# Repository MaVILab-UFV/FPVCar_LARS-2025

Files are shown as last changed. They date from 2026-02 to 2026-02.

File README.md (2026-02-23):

# FPVcar: An Affordable Robotic Platform to Support Computer Vision Education, from Hardware Design to User-Friendly Programming

This repository contains the full source code and 3D design files for the FPVCar project.

FPVcar is a low-cost robotic platform designed to facilitate hands-on Computer Vision and Robotics education, enabling 
users to control a robot through high-level Python commands while receiving real-time video feedback.

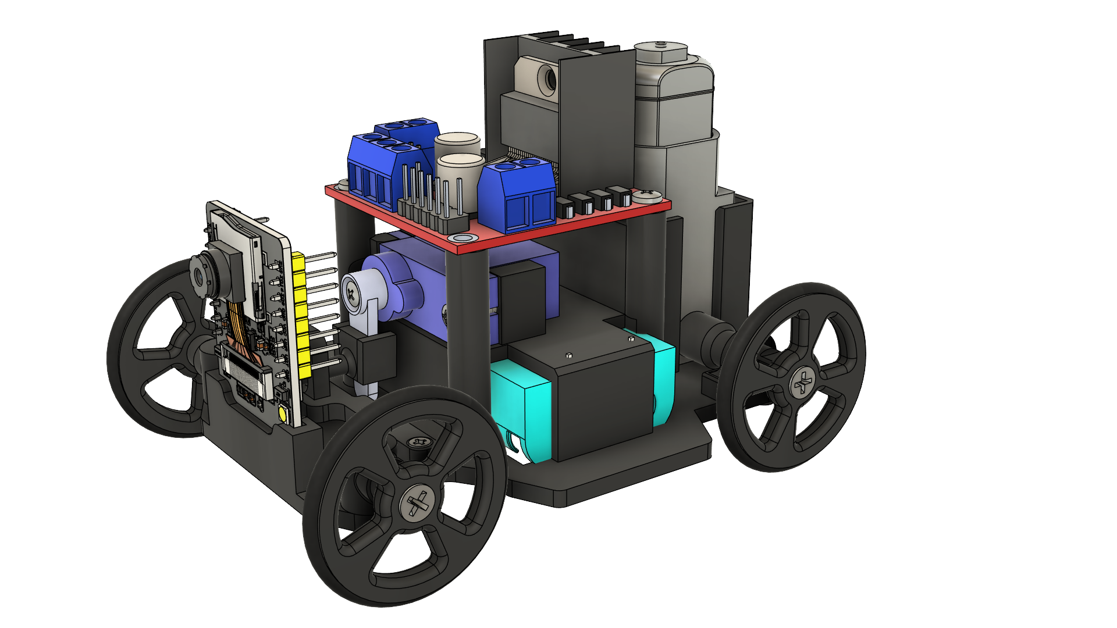
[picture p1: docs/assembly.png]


## Prerequisites
 - Python 3.6+ and python3-venv.
 - PlatformIO, for firmware deployment. 
 - OpenCV, Websockets and Pandas, for the control software.

## Getting Started

### 1. Clone the Repository

First, clone this repository to your local machine:

```bash
git clone https://github.com/MaVILab-UFV/FPVCar_LARS-2025.git
cd FPVCar_LARS-2025
```

### 2. Firmware Deployment
The firmware can be flashed using PlatformIO either via the VS Code Interface or the command line.

#### Setup Credentials
Before flashing, navigate to `firmware/include/` and update `wifikeys.h` with the desired network credentials.

#### 2.1 Using VS Code Extension
Open the `firmware/` folder in VS Code and click on the PlatformIO icon on the left sidebar. Then, under **Project Tasks**, click **Upload**.

#### 2.2 Using Command Line
If you have PlatformIO Core installed, run the following commands in your terminal:
```bash
cd firmware
pio run --target upload
```
### 3. Software Installation
Follow these steps to create a virtual enviroment and install the fpvcar library:
```bash
# Navigate to the software directory
cd software

# Create and activate a virtual environment
python3 -m venv venv
source venv/bin/activate

# Install build tools and dependencies
pip install wheel setuptools
pip install opencv-python websockets

# Build and install the FPVcar package
python3 setup.py bdist_wheel
pip install ./dist/fpvcar-0.1.2-py3-none-any.whl
```

## Running the FPVCar
After turning on the robot and connecting to the same network, you can run various control scripts. Here is an example:
```python
from fpvcar import FPVCar
from fpvcar.command import MoveForwardStraight, Stop

# Initialize the car with its Access Point IP
car = FPVCar(ip='192.168.4.1')
car.start()

# Example: Move forward
car.run(lambda frame, info: MoveForwardStraight)
```
This repository also provides ready-to-use scripts for validation and testing in the `software/tests/` directory.

## Authors

## Laboratory

## Acknowlwdgements

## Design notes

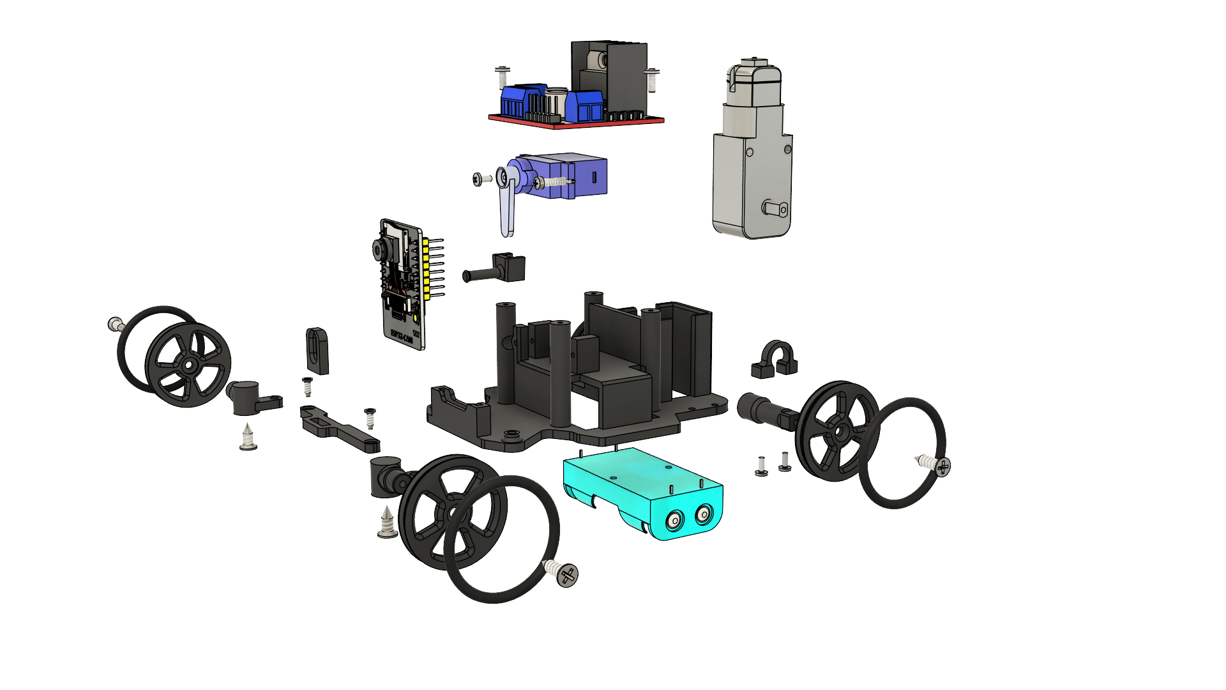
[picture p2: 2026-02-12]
docs/expanded_view.png

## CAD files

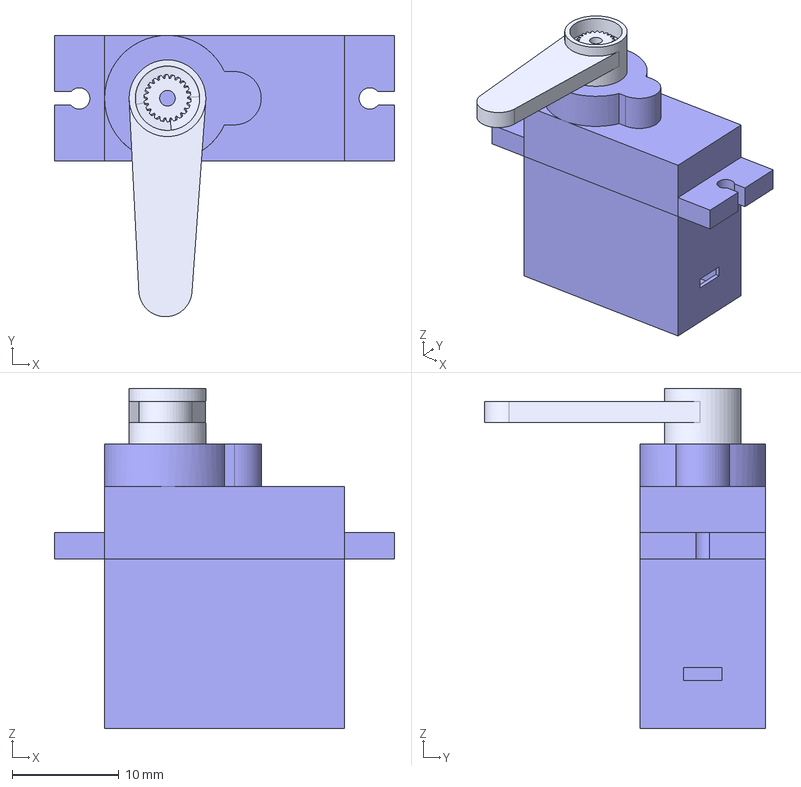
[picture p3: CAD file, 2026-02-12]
hardware/cad/step/servo_motor_assembly.step
31.9 x 26.4 x 31.9 mm
lower cover
Part6^servo motor assembley
Part10^servo motor assembley
upper cover
Part14^servo motor assembley

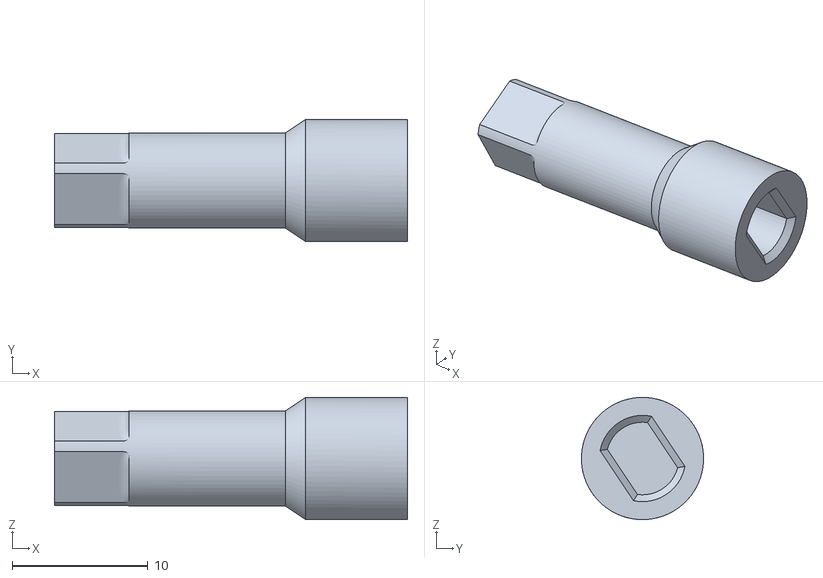
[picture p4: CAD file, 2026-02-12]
hardware/3d_printing/rear_axle.stl
26.0 x 9.00 x 9.00

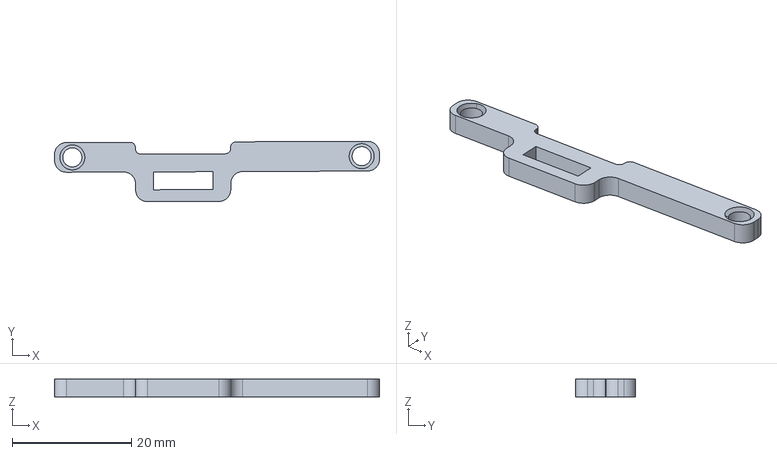
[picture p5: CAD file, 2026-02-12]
hardware/cad/step/steering_arm.step
54.6 x 10.1 x 3.00 mm

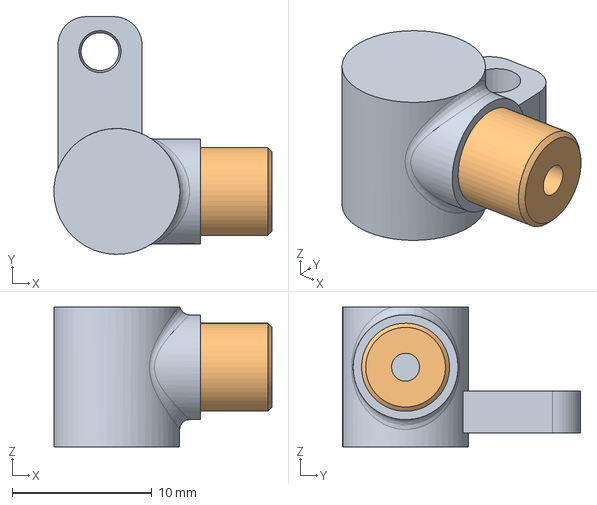
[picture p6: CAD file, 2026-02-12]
hardware/cad/step/left_pivot.step
15.6 x 17.0 x 10.0 mm

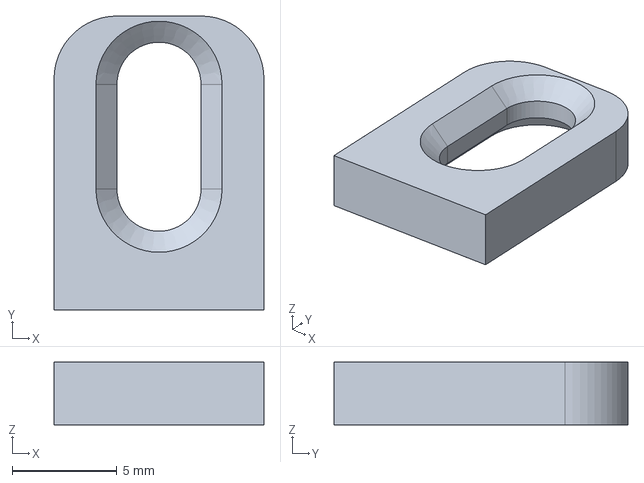
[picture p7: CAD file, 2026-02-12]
hardware/cad/step/arm_fitting.step
10.00 x 14.0 x 3.00 mm

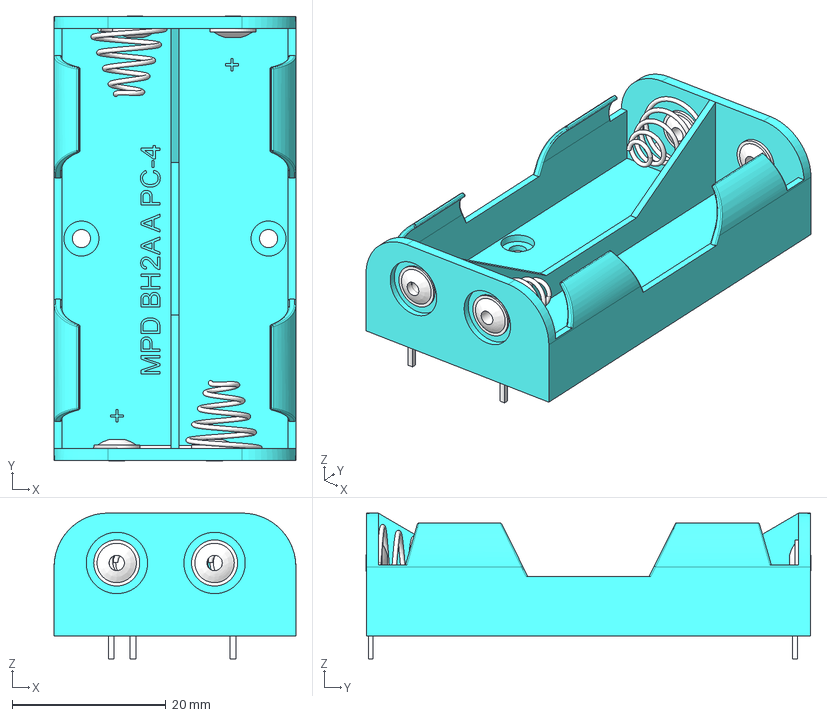
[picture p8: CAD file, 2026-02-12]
hardware/cad/step/AA_battery_holder.step
31.5 x 58.0 x 19.0 mm

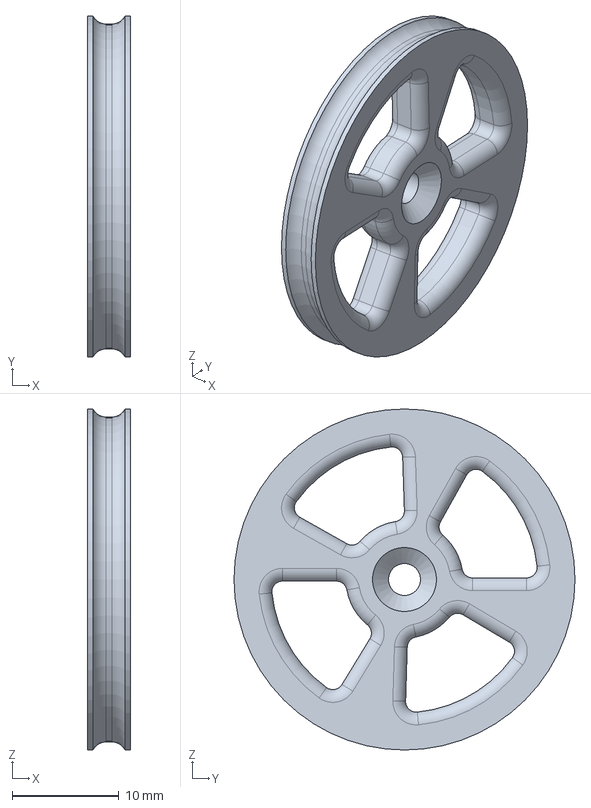
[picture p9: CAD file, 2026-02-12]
hardware/cad/step/rear_wheel.step
4.00 x 32.0 x 32.0 mm

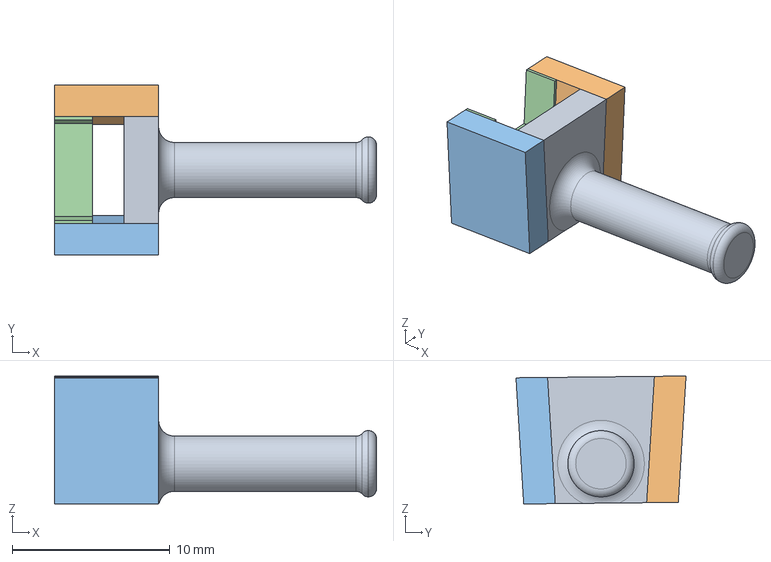
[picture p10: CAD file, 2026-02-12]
hardware/cad/step/servo_steering_adapter.step
20.4 x 10.8 x 8.11 mm

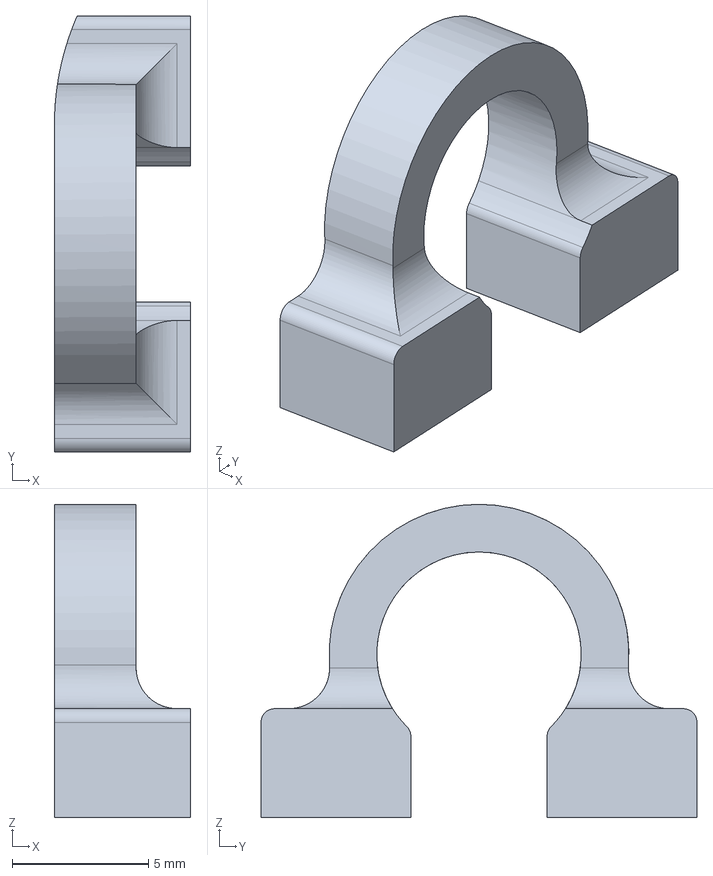
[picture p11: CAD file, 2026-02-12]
hardware/cad/step/right_rear_axle_support.step
5.00 x 16.0 x 11.5 mm

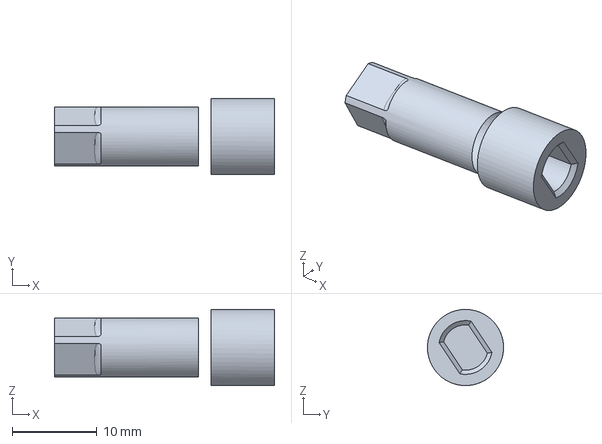
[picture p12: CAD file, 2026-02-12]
hardware/cad/step/right_rear_steering_axle.step
26.0 x 9.00 x 9.00 mm

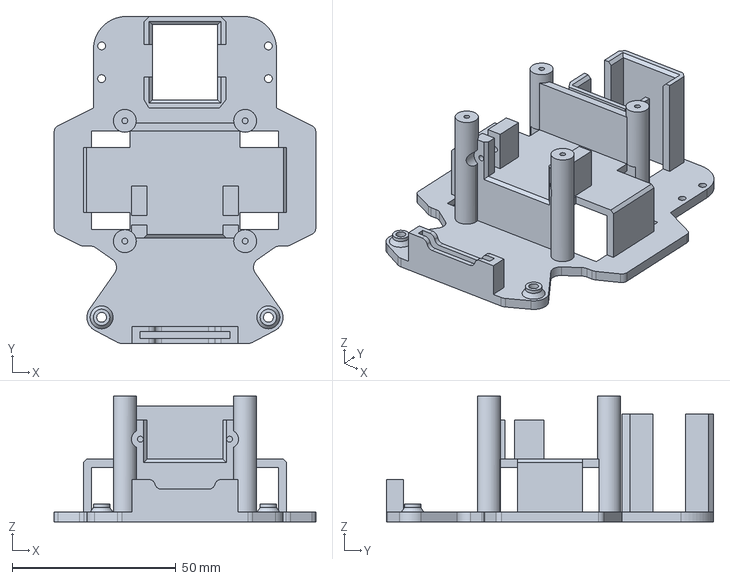
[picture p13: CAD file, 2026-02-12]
hardware/cad/step/chassis.step
80.0 x 100.0 x 38.5 mm

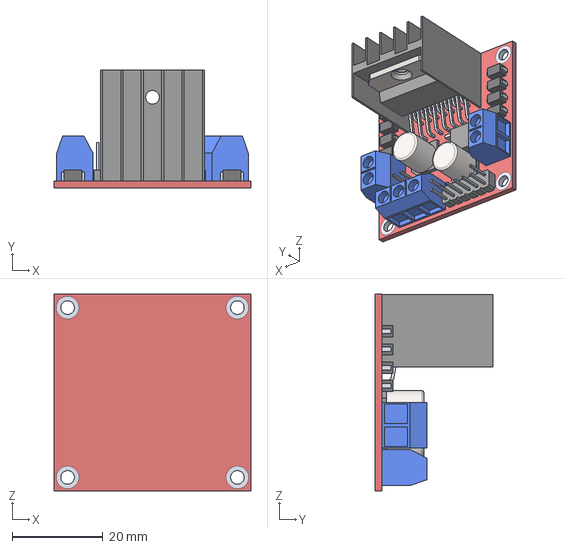
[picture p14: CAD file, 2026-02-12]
hardware/cad/step/L298N_motor_driver.step
43.5 x 26.0 x 43.5 mm

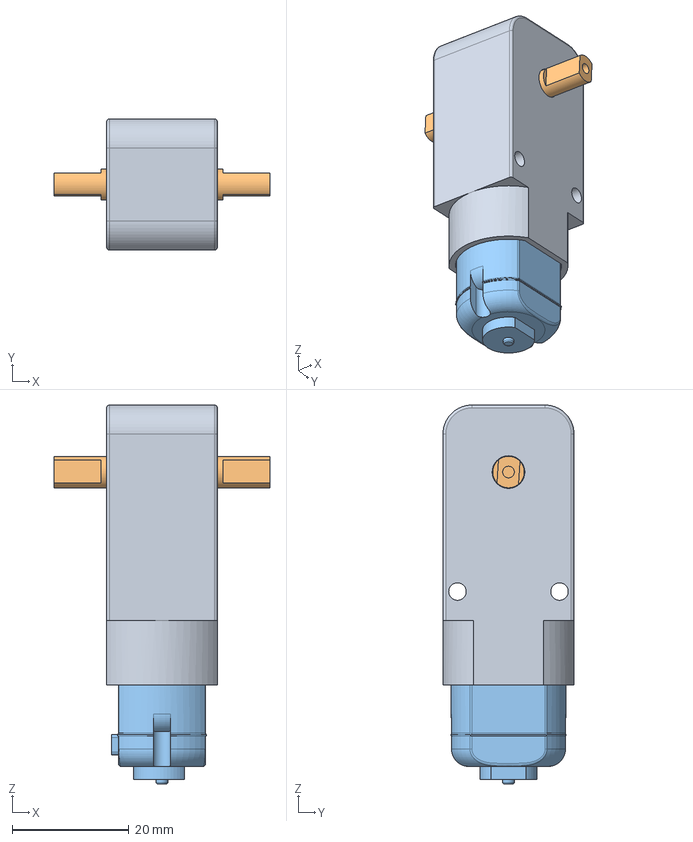
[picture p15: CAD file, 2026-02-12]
hardware/cad/step/DC_motor_gearbox.step
37.0 x 22.5 x 65.0 mm
Gearbox
output shaft
motor

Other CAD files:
hardware/cad/step/right_pivot.step
hardware/cad/step/front_wheel.step
hardware/cad/step/left_rear_axle_support.step
hardware/3d_printing/arm_fitting.stl
hardware/3d_printing/chassis.stl
hardware/3d_printing/front_wheel.stl
hardware/3d_printing/left_pivot.stl
hardware/3d_printing/left_rear_axle_support.stl
hardware/3d_printing/rear_wheel.stl
hardware/3d_printing/right_pivot.stl
hardware/3d_printing/right_rear_axle_support.stl
hardware/3d_printing/servo_steering_adapter.stl
hardware/3d_printing/steering_arm.stl
hardware/cad/fusion360/063d16ca-c277-448f-8e48-6c60c6a685a3.f3d
hardware/cad/fusion360/1c37564c-319c-4f1c-85a2-626b4ae4cbee.f3d
hardware/cad/fusion360/2c9e7e17-119f-482e-b289-b208573ba1ca.f3d
hardware/cad/fusion360/2f7473f9-b099-412f-9152-2018551abb9a.f3d
hardware/cad/fusion360/327ee1e9-15fe-45b5-88e0-88bf1f6365e6.f3d
hardware/cad/fusion360/3318b660-f424-4180-807f-c482663afaa1.f3d
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

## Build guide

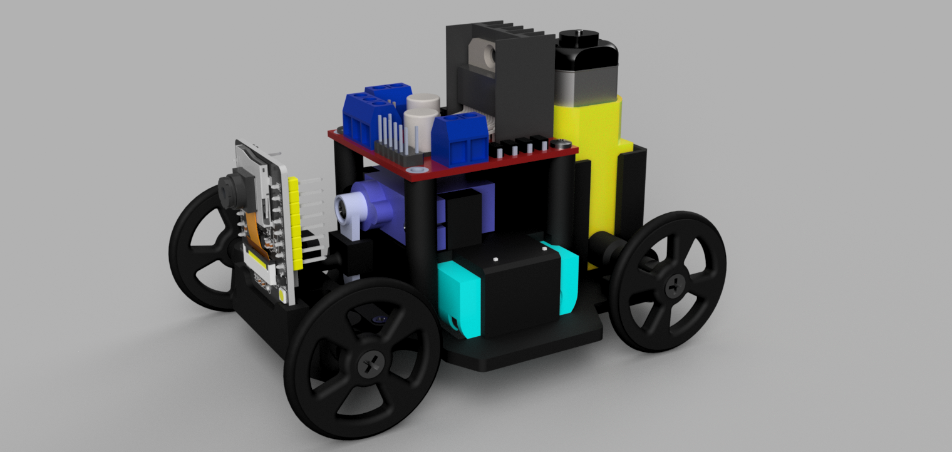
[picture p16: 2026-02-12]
docs/render_assembly.png

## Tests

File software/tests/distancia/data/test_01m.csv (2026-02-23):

timestamp | latencia | fps
1734579854.5667 | 0.0318598747253418 | 5.765084826548854e-10
1734579854.5730 | 0.0318598747253418 | 159.40650653694132
1734579854.7389 | 0.0318598747253418 | 6.0275112810047995
1734579854.8030 | 0.0318598747253418 | 15.611069135572718
1734579854.9621 | 0.0318598747253418 | 6.28610652334863
1734579855.0577 | 0.0318598747253418 | 10.455595606674743
1734579855.1378 | 0.0318598747253418 | 12.489403833498596
1734579855.2801 | 0.0318598747253418 | 7.0271532709748
1734579855.3884 | 0.01592540740966797 | 9.231560227492825
1734579855.4774 | 0.01592540740966797 | 11.240142139706395
1734579855.5446 | 0.01592540740966797 | 14.878377899015984
1734579855.6860 | 0.01592540740966797 | 7.069365438128996
1734579855.7816 | 0.01592540740966797 | 10.462689769059224
1734579855.8919 | 0.01592540740966797 | 9.068824230211224
1734579855.9713 | 0.01592540740966797 | 12.59286035968415
1734579856.1451 | 0.01592540740966797 | 5.752351380930568
1734579856.2254 | 0.01592540740966797 | 12.45025453789869
1734579856.3200 | 0.01592540740966797 | 10.57362683903236
1734579856.4154 | 0.01592540740966797 | 10.482851008845046
1734579856.5572 | 0.01592540740966797 | 7.052652287742155
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

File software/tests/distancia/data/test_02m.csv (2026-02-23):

timestamp | latencia | fps
1734580026.5213 | 0.015857219696044922 | 5.765084255037093e-10
1734580026.5290 | 0.015857219696044922 | 130.7614415762564
1734580026.6223 | 0.015857219696044922 | 10.711997384766264
1734580026.7422 | 0.015857219696044922 | 8.342275004624316
1734580026.7900 | 0.015857219696044922 | 20.906709201475426
1734580026.9493 | 0.015857219696044922 | 6.281117280955547
1734580027.0127 | 0.015857219696044922 | 15.767230296149826
1734580027.1719 | 0.015857219696044922 | 6.27999814338739
1734580027.2676 | 0.015857219696044922 | 10.451895857421952
1734580027.3311 | 0.015857219696044922 | 15.753491132261143
1734580027.4790 | 0.015857219696044922 | 6.760481290748934
1734580027.5201 | 0.03456592559814453 | 24.34741015504821
1734580027.6833 | 0.03456592559814453 | 6.12708768229102
1734580027.7307 | 0.03456592559814453 | 21.06092362077017
1734580027.8903 | 0.03456592559814453 | 6.2683414907528485
1734580027.9385 | 0.03456592559814453 | 20.716295242611032
1734580028.1136 | 0.03456592559814453 | 5.714232776120216
1734580028.2086 | 0.03456592559814453 | 10.517285563476522
1734580028.2732 | 0.03456592559814453 | 15.49629246485508
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

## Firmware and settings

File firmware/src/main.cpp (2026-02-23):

#include "OV2640.h"
#include <WiFi.h>
#include <WiFiClient.h>

#include "OV2640Streamer.h"
#include "CRtspSession.h"

#include "car.h"
#include "../include/wifikeys.h"

#include <WebSocketsServer.h>
#include <ArduinoJson.h>

OV2640 cam;
WiFiServer rtspServer(8554);
WebSocketsServer wsServer(81);

CStreamer *streamer;
CRtspSession *session;
WiFiClient client;

void debug(const char *message) {
    JsonDocument doc;
    doc["debug"] = message;
    String json;
    serializeJson(doc, json);
    wsServer.broadcastTXT(json);
}

void debug(String message) {
    JsonDocument doc;
    doc["debug"] = message;
    String json;
    serializeJson(doc, json);
    wsServer.broadcastTXT(json);
}

void webSocketEvent(uint8_t num, WStype_t type, uint8_t * payload, size_t length) {
    JsonDocument doc;

    switch(type) {

    case WStype_CONNECTED: {
        IPAddress ip = wsServer.remoteIP(num);
        String message = "Websocket connected: " + ip.toString();
        Serial.println(message);
        debug(message);
        break;
    };

    case WStype_TEXT: {
        DeserializationError error = deserializeJson(doc, (char*)payload);
        if(error.code() == DeserializationError::Code::Ok) {
            if(doc.containsKey("time")) {
                carSetRunTime(doc["time"]);
            }
            if(doc.containsKey("speed")) {
                carSetSpeed(doc["speed"]);
            }
            if(doc.containsKey("turn")) {
                carSetTurn(doc["turn"]);
            }
            if(doc.containsKey("ping")) {
                JsonDocument res;
                res["pong"] = doc["ping"];
                String json;
                serializeJson(res, json);
                wsServer.broadcastTXT(json);
            }
        } else {
            debug("Erro ao desserializar JSON");
            Serial.println("Erro ao desserializar JSON");
        }
        break;
    };

    default:
        break;
    }
}

void updateCarTask(void *params) {
    for(;;) {
        unsigned long now = millis();
        if (!carIsUpdated()) {
            carSetSpeed(DEF_SPEED);
        }
        vTaskDelay(pdMS_TO_TICKS(50));
    }
}

void wsLoopTask(void *params) {
    for(;;) {
        wsServer.loop();
        vTaskDelay(pdMS_TO_TICKS(10));
    }
}

void rtspLoopTask(void *params) {
    static uint32_t lastimage = millis();
    uint32_t msecPerFrame = 100;
    for(;;) {
        if(session) {
            session->handleRequests(0);
            uint32_t now = millis();
            if(now > lastimage + msecPerFrame || now < lastimage) {
                session->broadcastCurrentFrame(now);
                lastimage = now;
                now = millis();
                if(now > lastimage + msecPerFrame) {
                    printf("warning exceeding max frame rate of %d ms\n", now - lastimage);
                    char msg[128];
                    sprintf(msg, "Warning exceeding max frame rate. %d ms", now - lastimage);
                    debug(msg);
                }
            }
            if(session->m_stopped) {
                delete session;
                delete streamer;
                session = NULL;
                streamer = NULL;
            }
        }
        else {
            client = rtspServer.accept();
            if(client) {
                streamer = new OV2640Streamer(&client, cam);
                session = new CRtspSession(&client, streamer);
            }
        }
        vTaskDelay(pdMS_TO_TICKS(10));
    }
}

void scanNetworks() {
    int n = WiFi.scanNetworks();
    if(n == 0) {
        Serial.println("No Networks");
        return;
    }
    Serial.print(n);
    Serial.println(" networks found");
    Serial.println("Nr | SSID                             | RSSI | CH | Encryption");
    for(int i=0; i<n; i++) {
        Serial.printf("%2d",i + 1);
        Serial.print(" | ");
        Serial.printf("%-32.32s", WiFi.SSID(i).c_str());
        Serial.print(" | ");
        Serial.printf("%4d", WiFi.RSSI(i));
        Serial.print(" | ");
        Serial.printf("%2d", WiFi.channel(i));
        Serial.print(" | ");
        switch (WiFi.encryptionType(i))
        {
        case WIFI_AUTH_OPEN:
            Serial.print("open");
            break;
        case WIFI_AUTH_WEP:
            Serial.print("WEP");
            break;
        case WIFI_AUTH_WPA_PSK:
            Serial.print("WPA");
            break;
        case WIFI_AUTH_WPA2_PSK:
            Serial.print("WPA2");
            break;
        case WIFI_AUTH_WPA_WPA2_PSK:
            Serial.print("WPA+WPA2");
            break;
        case WIFI_AUTH_WPA2_ENTERPRISE:
            Serial.print("WPA2-EAP");
            break;
        case WIFI_AUTH_WPA3_PSK:
            Serial.print("WPA3");
            break;
        case WIFI_AUTH_WPA2_WPA3_PSK:
            Serial.print("WPA2+WPA3");
            break;
        case WIFI_AUTH_WAPI_PSK:
            Serial.print("WAPI");
            break;
        default:
            Serial.print("unknown");
        }
        Serial.println();
        delay(10);
    }
}

void setup() {
    carInit();

    Serial.begin(115200);

    camera_config_t config = esp32cam_aithinker_config;
    config.frame_size = FRAMESIZE_VGA;
    config.grab_mode = CAMERA_GRAB_LATEST;

    cam.init(config);

    WiFi.mode(WIFI_AP);
    WiFi.softAP(ssid, password);

    wsServer.begin();
    wsServer.onEvent(webSocketEvent);

    rtspServer.begin();

    xTaskCreate(updateCarTask, "update car", 4096, NULL, 1, NULL);
    xTaskCreate(wsLoopTask, "websocket loop", 4096, NULL, 2, NULL);
    xTaskCreate(rtspLoopTask, "rtsp loop", 4096, NULL, 2, NULL);
}

void loop() {}

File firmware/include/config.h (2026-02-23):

#ifndef __CONFIG__
#define __CONFIG__

#define configSERVO_PIN 15
// #define configSERVO_MIN_ANGLE 30
// #define configSERVO_MAX_ANGLE 90
#define configSERVO_MIN_ANGLE 0
#define configSERVO_MAX_ANGLE 180
#define configSERVO_DEG_PER_SEC 100

#define configMOTOR1_PIN 12
#define configMOTOR2_PIN 13
#define configMOTOR_MAX_SPEED 255

// #define configDEBUG

#define configUSE_ACESS_POINT

#endif

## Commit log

2026-02-12 Add editable step CAD models
    [AA_battery_holder.step, DC_motor_gearbox.step, L298N_motor_driver.step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]
2026-02-12 Add editable fusion360 CAD models
    [063d16ca-c277-448f-8e48-6c60c6a685a3.f3d, 1c37564c-319c-4f1c-85a2-626b4ae4cbee.f3d, 2c9e7e17-119f-482e-b289-b208573ba1ca.f3d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]
2026-02-12 Add stl files for 3D printing.
    [arm_fitting.stl, chassis.stl, front_wheel.stl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]
2026-02-23 Add ESP32-CAM control logic (firmware).
2026-02-23 Add data analysis tools and fpvcar library.
    [test_01m.csv, test_02m.csv, test_03m.csv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]
